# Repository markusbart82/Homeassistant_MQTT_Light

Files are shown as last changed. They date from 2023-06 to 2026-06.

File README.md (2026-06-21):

# Homeassistant MQTT Light
Homeassistant compatible MQTT Light implementation for RGB+CCT LEDs. Uses ESP8266 and PCA9685.

The idea started because I wanted "white with a color tint" smart lights. But apparently, this is not supported by smart home tech yet. It's either RGB, or white, never a mix of these. So this lamp here identifies as RGB, but mixes white with it.

# How Color Mixing Works

This lamp can display both **colored light** and **tunable white** (from warm 2300K to cool 7000K), and uniquely, it can **mix white with color** — producing effects like "pink-tinted white" or "blue-tinted daylight" that most smart lights can't do.

## The Color Pipeline

Here's what happens internally when you send a color command:

1. **Input from Home Assistant**: You send RGB values (0-255) and a color temperature in mireds (142–435 mireds = 7000K–2300K)
2. **White extraction**: The algorithm finds the achromatic (gray/white) component by taking `min(R, G, B)` — this is the amount of white already present in the color
3. **Color separation**: The white component is subtracted from R, G, B, leaving only the pure chromatic (saturated) colors
4. **White distribution**: The extracted white is split between warm white (WW) and cold white (CW) LEDs based on the requested color temperature
5. **PWM output**: All 5 channels (R, G, B, WW, CW) are scaled to 12-bit resolution (0-4095) and sent to the PCA9685 PWM driver

## Examples

### Pure white with temperature
| Input | Output (R,G,B,WW,CW) |
|---|---|
| Warm white (2300K) | (0, 0, 0, 4095, 0) |
| Neutral white | (0, 0, 0, 2048, 2048) |
| Cool white (7000K) | (0, 0, 0, 0, 4095) |

### White with a color tint
| Input | What you see |
|---|---|
| RGB(255,200,200) + 4000K | A soft pink-tinted white |
| RGB(200,220,255) + 5000K | A cool blue-tinted white |
| RGB(255,255,255) + 3500K | Pure warm white (no color tint) |

### Full color
| Input | What you see |
|---|---|
| RGB(255,0,0) + any temp | Pure red (white channels off, `min(255,0,0)=0`) |
| RGB(128,64,32) + 3000K | Orange with warm white boost (`min(128,64,32)=32` → WW adds white) |

## Why This Matters

Traditional smart lights force you to choose: RGB *or* white. With this lamp, you get both simultaneously — perfect for ambient lighting where you want a colored accent light that still feels natural and bright.

# Invisible color temperature updates

Most smart lamps only let you update the color temperature while they are on. So they turn on with the previous color temperature and then dim to the right one. To combat this behavior, send a message with `brightness=1` and the desired color temperature to do an invisible update. The lamp will remain in its previous state (OFF, that is). Such low brightness values usually are not shown in most lamps, either.

# Homeassistant integration

The lamp supports autodiscovery and identifies as "ESP-dimmer-NUMBER", where the number is derived from the MAC address. Supported features:

- JSON schema
- ON/OFF
- Brightness
- Color temperature
- RGB
- Transitions
- Flashing

# Effects

The lamp supports the following effects:

- **Colorwheel** — slowly changes through the RGB spectrum
- **Undulation** — slowly undulates randomly near the previously selected color

# Stand-alone mode

As a fallback when Home Assistant is unavailable:

- On powerup, the lamp turns on with neutral white
- WiFi/MQTT reconnection is handled automatically in the main loop

# Hardware

The lamp uses the PCA9685 PWM driver IC (16 channels, 12 bits, up to 1.5kHz PWM, I2C at 400kHz) to interface with the LEDs. Currently, channels 0–4 are assigned R, G, B, WW, CW.

## Ledcontroller_3x

This PCB includes the ESP8266, PCA9685 and BLM3400 MOSFETs, for controlling 24V LED strips with a common +24V.

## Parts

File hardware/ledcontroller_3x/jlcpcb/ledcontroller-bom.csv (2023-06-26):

Designator | Footprint | Comment | LCSC Part Number
C7,C6,C5,C4,C3 | CP_Elec_5x5.4 | 10uF 35V
R14,R9,R18,R11,R10,R8,R22,R17,R13,R20,R19,R2,R15,R21,R1,R16,R12 | R_0805_2012Metric | 1k
R3,R7,R6,R23,R24,R25,R4,R5 | R_0805_2012Metric | 10k
Q3,Q10,Q4,Q5,Q1,Q11,Q12,Q6,Q7,Q14,Q15,Q13,Q8,Q2,Q9 | SOT-23 | BLM3400
Q16,Q17 | SOT-23 | MMS9013-H-TP
C2,C1 | C_0805_2012Metric | 100nF
U2 | TSSOP-28_4.4x9.7mm_P0.65mm | PCA9685PW

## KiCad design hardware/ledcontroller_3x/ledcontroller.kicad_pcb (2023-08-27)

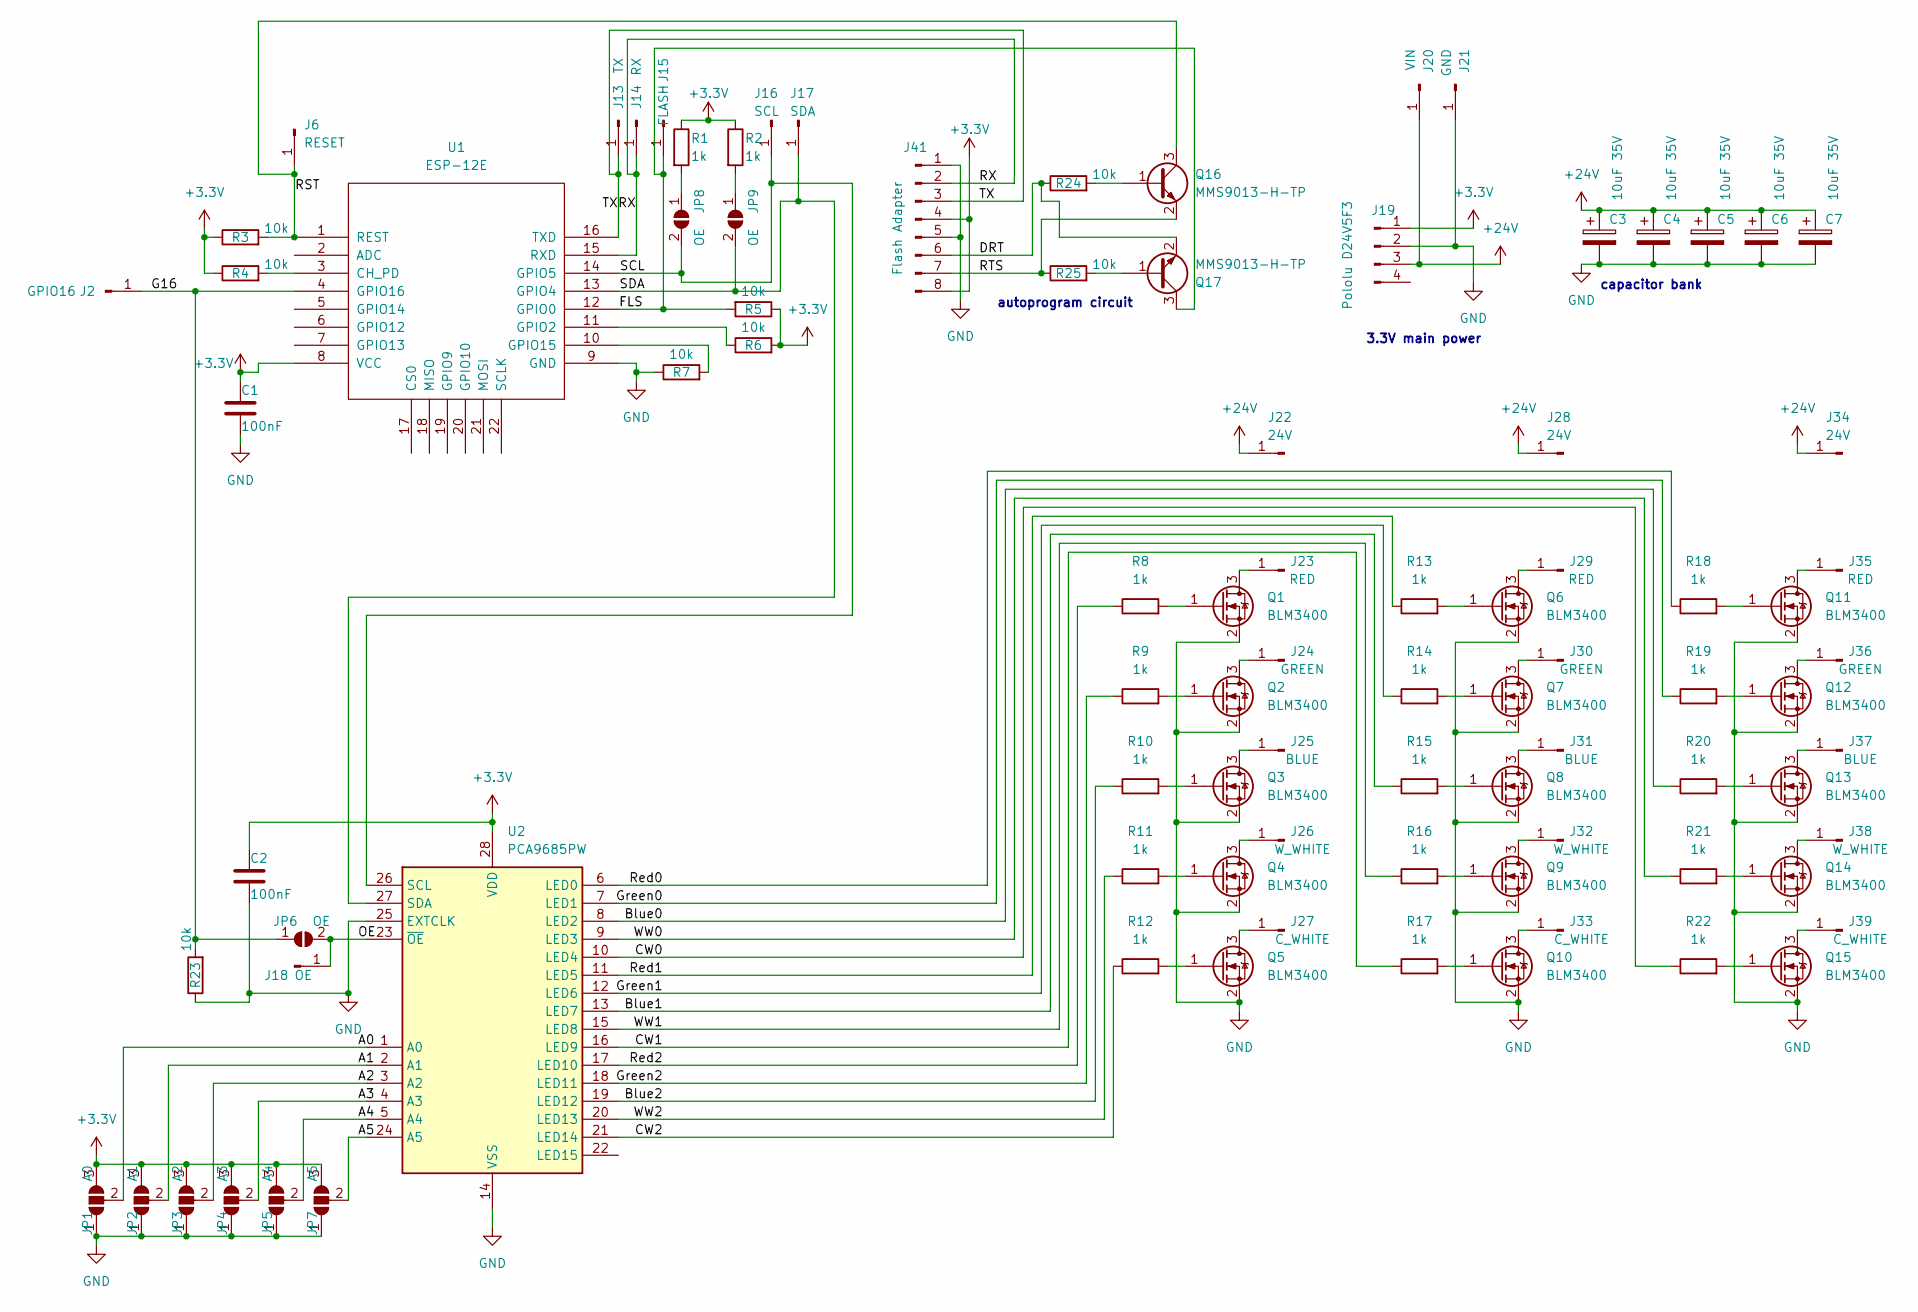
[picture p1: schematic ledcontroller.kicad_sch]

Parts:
C1, C2: 100nF; C_0805_2012Metric
C3, C4, C5, C6, C7: 10uF 35V; CP_Elec_5x5.4
J2: GPIO16; TestPoint_Pad_2.0x2.0mm
J6: RESET; TestPoint_Pad_2.0x2.0mm
J13: TX; TestPoint_Pad_2.0x2.0mm
J14: RX; TestPoint_Pad_2.0x2.0mm
J15: FLASH; TestPoint_Pad_2.0x2.0mm
J16: SCL; TestPoint_Pad_2.0x2.0mm
J17: SDA; TestPoint_Pad_2.0x2.0mm
J18: OE; TestPoint_Pad_2.0x2.0mm
J19: Pololu D24V5F3; PinHeader_1x04_P2.54mm_Vertical
J20: VIN; TestPoint_Pad_4.0x4.0mm
J21: GND; TestPoint_Pad_4.0x4.0mm
J22, J28, J34: 24V; TestPoint_Pad_3.0x3.0mm
J23, J29, J35: RED; TestPoint_Pad_3.0x3.0mm
J24, J30, J36: GREEN; TestPoint_Pad_3.0x3.0mm
J25, J31, J37: BLUE; TestPoint_Pad_3.0x3.0mm
J26, J32, J38: W_WHITE; TestPoint_Pad_3.0x3.0mm
J27, J33, J39: C_WHITE; TestPoint_Pad_3.0x3.0mm
J41: Flash Adapter; WingTAT_ED08BGFBK
JP1: A0; SolderJumper-3_P1.3mm_Open_Pad1.0x1.5mm
JP2: A1; SolderJumper-3_P1.3mm_Open_Pad1.0x1.5mm
JP3: A2; SolderJumper-3_P1.3mm_Open_Pad1.0x1.5mm
JP4: A3; SolderJumper-3_P1.3mm_Open_Pad1.0x1.5mm
JP5: A4; SolderJumper-3_P1.3mm_Open_Pad1.0x1.5mm
JP6, JP8, JP9: OE; SolderJumper-2_P1.3mm_Open_Pad1.0x1.5mm
JP7: A5; SolderJumper-3_P1.3mm_Open_Pad1.0x1.5mm
Q1, Q2, Q3, Q4, Q5, Q6, Q7, Q8, Q9, Q10, Q11, Q12, Q13, Q14, Q15: BLM3400; SOT-23
Q16, Q17: MMS9013-H-TP; SOT-23
R1, R2, R8, R9, R10, R11, R12, R13, R14, R15, R16, R17, R18, R19, R20, R21, R22: 1k; R_0805_2012Metric
R3, R4, R5, R6, R7, R23, R24, R25: 10k; R_0805_2012Metric
U1: ESP-12E; ESP-12E_SMD
U2: PCA9685PW; TSSOP-28_4.4x9.7mm_P0.65mm

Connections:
+3.3V: C1.1, C2.1, J19.1, J41.4, J41.8, JP1.3 (B), JP2.3 (B), JP3.3 (B), JP4.3 (B), JP5.3 (B), JP7.3 (B), R1.1, R2.1, R3.1, R4.1, R5.1, R6.2, U1.8 (VCC), U2.28 (VDD)
+24V: C3.1, C4.1, C5.1, C6.1, C7.1, J19.3, J20.1, J22.1, J28.1, J34.1
/A0: JP1.2 (C), U2.1 (A0)
/A1: JP2.2 (C), U2.2 (A1)
/A2: JP3.2 (C), U2.3 (A2)
/A3: JP4.2 (C), U2.4 (A3)
/A4: JP5.2 (C), U2.5 (A4)
/A5: JP7.2 (C), U2.24 (A5)
/ADC: U1.2 (ADC)
/Blue0: R20.1, U2.8 (LED2)
/Blue1: R15.1, U2.13 (LED7)
/Blue2: R10.1, U2.19 (LED12)
/CS0: U1.17 (CS0)
/CW0: R22.1, U2.10 (LED4)
/CW1: R17.1, U2.16 (LED9)
/CW2: R12.1, U2.21 (LED14)
/DRT: J41.6, Q17.2 (E), R24.1
/FLS: J15.1, Q17.3 (C), R5.2, U1.12 (GPIO0)
/G9: U1.19 (GPIO9)
/G10: U1.20 (GPIO10)
/G12: U1.6 (GPIO12)
/G13: U1.7 (GPIO13)
/G14: U1.5 (GPIO14)
/G16: J2.1, JP6.1 (A), R23.2, U1.4 (GPIO16)
/Green0: R19.1, U2.7 (LED1)
/Green1: R14.1, U2.12 (LED6)
/Green2: R9.1, U2.18 (LED11)
/MISO: U1.18 (MISO)
/MOSI: U1.21 (MOSI)
/OE: J18.1, JP6.2 (B), U2.23 (~OE)
/RST: J6.1, Q16.3 (C), R3.2, U1.1 (REST)
/RTS: J41.7, Q16.2 (E), R25.1
/RX: J14.1, J41.2, U1.15 (RXD)
/Red0: R18.1, U2.6 (LED0)
/Red1: R13.1, U2.11 (LED5)
/Red2: R8.1, U2.17 (LED10)
/SCL: J16.1, JP8.2 (B), U1.14 (GPIO5), U2.26 (SCL)
/SCLK: U1.22 (SCLK)
/SDA: J17.1, JP9.2 (B), U1.13 (GPIO4), U2.27 (SDA)
/TX: J13.1, J41.3, U1.16 (TXD)
/WW0: R21.1, U2.9 (LED3)
/WW1: R16.1, U2.15 (LED8)
/WW2: R11.1, U2.20 (LED13)
GND: C1.2, C2.2, C3.2, C4.2, C5.2, C6.2, C7.2, J19.2, J21.1, J41.1, J41.5, JP1.1 (A), JP2.1 (A), JP3.1 (A), JP4.1 (A), JP5.1 (A), JP7.1 (A), Q1.2 (S), Q2.2 (S), Q3.2 (S), Q4.2 (S), Q5.2 (S), Q6.2 (S), Q7.2 (S), Q8.2 (S), Q9.2 (S), Q10.2 (S), Q11.2 (S), Q12.2 (S), Q13.2 (S), Q14.2 (S), Q15.2 (S), R7.1, R23.1, U1.9 (GND), U2.14 (VSS), U2.25 (EXTCLK)
unnamed: J23.1, Q1.3 (D)
unnamed: J24.1, Q2.3 (D)
unnamed: J25.1, Q3.3 (D)
unnamed: J26.1, Q4.3 (D)
unnamed: J27.1, Q5.3 (D)
unnamed: J29.1, Q6.3 (D)
unnamed: J30.1, Q7.3 (D)
unnamed: J31.1, Q8.3 (D)
unnamed: J32.1, Q9.3 (D)
unnamed: J33.1, Q10.3 (D)
unnamed: J35.1, Q11.3 (D)
unnamed: J36.1, Q12.3 (D)
unnamed: J37.1, Q13.3 (D)
unnamed: J38.1, Q14.3 (D)
unnamed: J39.1, Q15.3 (D)
unnamed: JP8.1 (A), R1.2
unnamed: JP9.1 (A), R2.2
unnamed: Q1.1 (G), R8.2
unnamed: Q2.1 (G), R9.2
unnamed: Q3.1 (G), R10.2
unnamed: Q4.1 (G), R11.2
unnamed: Q5.1 (G), R12.2
unnamed: Q6.1 (G), R13.2
unnamed: Q7.1 (G), R14.2
unnamed: Q8.1 (G), R15.2
unnamed: Q9.1 (G), R16.2
unnamed: Q10.1 (G), R17.2
unnamed: Q11.1 (G), R18.2
unnamed: Q12.1 (G), R19.2
unnamed: Q13.1 (G), R20.2
unnamed: Q14.1 (G), R21.2
unnamed: Q15.1 (G), R22.2
unnamed: Q16.1 (B), R24.2
unnamed: Q17.1 (B), R25.2
unnamed: R4.2, U1.3 (CH_PD)
unnamed: R6.1, U1.11 (GPIO2)
unnamed: R7.2, U1.10 (GPIO15)

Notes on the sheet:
capacitor bank
autoprogram circuit
3.3V main power

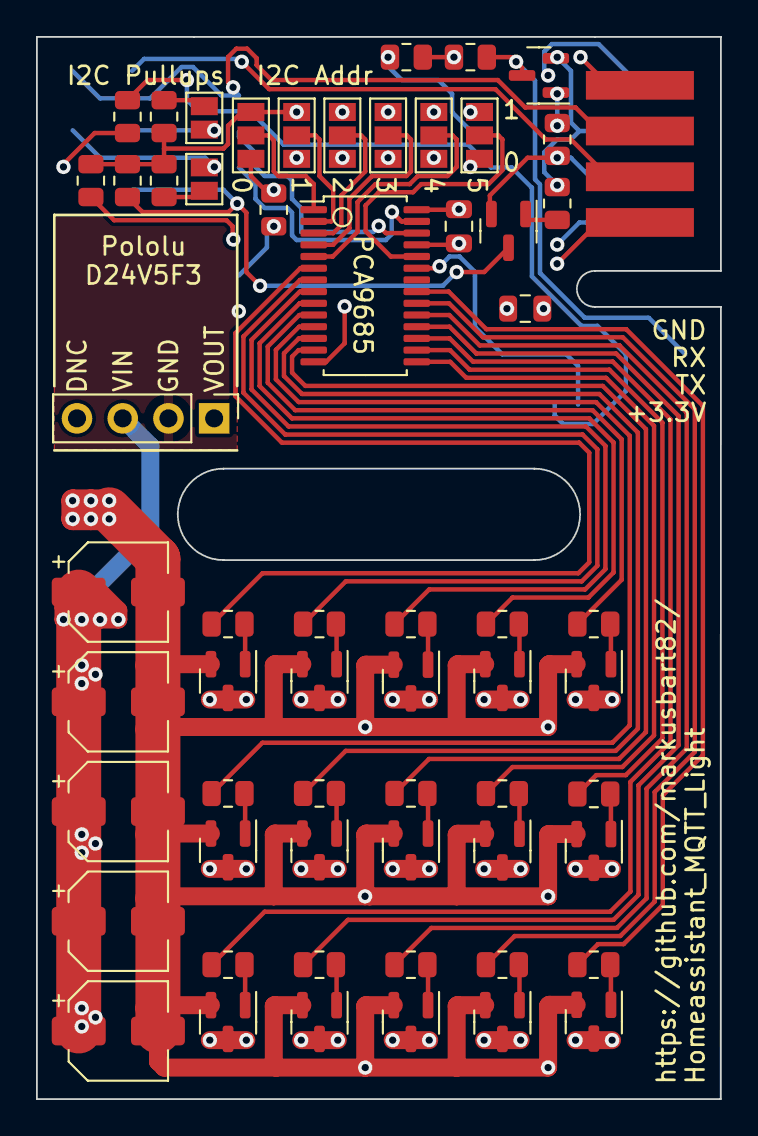
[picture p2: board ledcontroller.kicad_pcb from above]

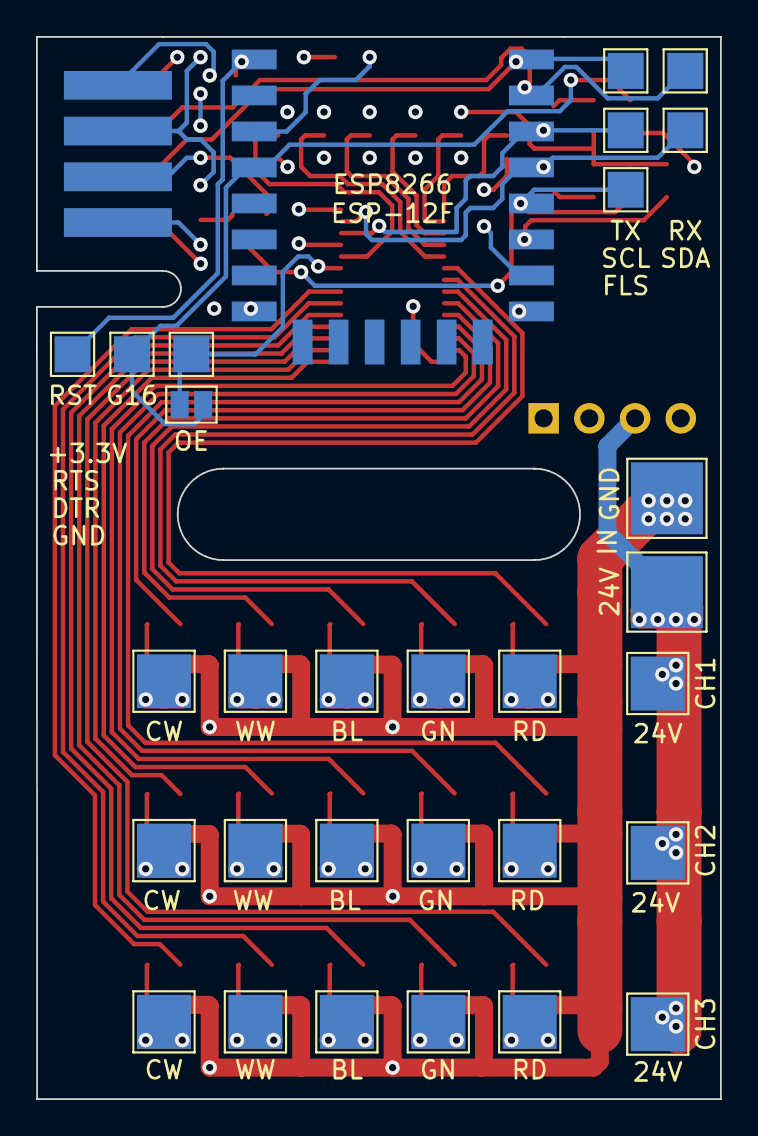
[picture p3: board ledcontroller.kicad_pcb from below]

Board: 4 copper layers, 38.0 x 59.0 mm, 90 parts (30 on the bottom side), 71 nets.

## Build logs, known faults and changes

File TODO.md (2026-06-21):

# Get LEDs to light up correctly
* Is library called correctly?
* Are color values calculated correctly? Repeated "ON" commands lead to different white balance...

# Unburden the ISR for receiving a message
* add MessageHandler buffer to store received message and to process it later, during main loop
* add "memory busy" flag to avoid overwriting this buffer if messages come in too quickly (is this an issue?)

# Fix errors
* find cause for random reconnects (Wifi)

# Cleanup
* remove printlns from Channelmanager::loop()

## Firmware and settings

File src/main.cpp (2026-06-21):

#include <Arduino.h>
#include <ESP8266WiFi.h>
#include <PubSubClient.h>
#include <PCA9685.h>
#include "ArduinoJson.h"
#include "secrets.h"
#include "channel.h"
#include "channelmanager.h"
#include "colorhandler.h"
#include "messagehandler.h"
#include "controller.h"
#include "types.h"


// output enable (low = enabled)
#define OE_PIN 16

// I2C
#define SCL_PIN 5
#define SDA_PIN 4

Channelmanager channelmanager(3); // TODO: make this dynamic - for now, it's 3 static channels
Messagehandler messagehandler;
WiFiClient wifiClient;
PubSubClient pubSubClient(wifiClient);

// this function is the entry point for received messages
void receiveMessage(char* topic, byte* payload, unsigned int length) {
  Serial.println("receiveMessage");

  /* HomeAssistant will send these messages to the lamp using the UI:
   * OFF
   * ON
   * ON brightness
   * ON colortemp
   * ON RGB
   * ON effect
   * 
   * HomeAssistant will send these messages to the lamp using scripts:
   * ON brightness colortemp
   * ON transition
   * OFF transition
   * ON transition brightness
   * ON transition colortemp
   * ON transition brightness colortemp
   * ON flash RGB
   * ON flash brightness
   * ON flash colortemp
   * ON flash brightness colortemp
   * 
   * HomeAssistant will NOT send these messages:
   * OFF colortemp
   * ON brightness=0 colortemp
   * 
   * This lamp will use this message format to change the colortemp without turning on the lamp:
   * ON brightness=1 colortemp
   * And after the call, it reports back "OFF"
   */

  //TODO: move all of the following into the main loop, inside messageHandler.parseMessage, and have a buffer for the received values
   
  // call messagehandler to parse the message
  messagehandler.parseMessage(topic, payload, length);

  // temporary values for updating the channel
  uint16_t r = 0;
  uint16_t g = 0;
  uint16_t b = 0;
  uint16_t ww = 0;
  uint16_t cw = 0;
  uint8_t channelNumber = messagehandler.getChannelNumber();
  boolean writeUpdate = true; // set this variable to false if an update is not required

  // update channel(s) with data from the parsed message
  Channel* channel = channelmanager.getChannel(channelNumber);
  // check on/off state
  if(messagehandler.getState()){
    Serial.println("state is ON");
    // state is "ON"

    if(messagehandler.getEffect() != none){
      Serial.println("has effect");
      
      // if an effect is selected, use that
      channel->setEffect(messagehandler.getEffect());

    }else{
      Serial.println("has no effect");
      
      // if no effect is selected, disable effects and proceed
      channel->setEffect(none);

      // if color temperature is included, update the stored value
      if(messagehandler.getColortemp()!=UINT16_MAX){
        channel->setColorTemp(messagehandler.getColortemp());
      }

      // calculate colors to use for dim/flash
      if(messagehandler.getBrightness()>0){
        Serial.println("using brightness mode");
        // brightness is part of the message, go for uncolored mode
        if(messagehandler.getBrightness()==1){
          // special message to update color temperature and change nothing in the actual light
          writeUpdate = false; // do nothing, no changes to the light, just update the color temperature
        }else{
          // brightness >1, use it for RGB with stored color temperature
          uint8_t brightness = messagehandler.getBrightness();
          Colorhandler::rgb8ToRgbww12(brightness, brightness, brightness, channel->getColorTemp(), r, g, b, ww, cw);
        }
      }else if(messagehandler.getRed()>0 || messagehandler.getGreen()>0 || messagehandler.getBlue()>0){
        Serial.println("using RGB mode");
        // RGB is set, use it with stored color temperature
        Colorhandler::rgb8ToRgbww12(messagehandler.getRed(), messagehandler.getGreen(), messagehandler.getBlue(), channel->getColorTemp(), r, g, b, ww, cw);
      }else{
        // just "ON" command
        Colorhandler::rgb8ToRgbww12(255u, 255u, 255u, channel->getColorTemp(), r, g, b, ww, cw);
      }

      // dim or flash the lamp accordingly
      if(writeUpdate){ // skip the update for the invisible colortemp update
        if(messagehandler.getFlashTime()>0){
          Serial.println("flashing");
          // flashing
          channel->flashColor(r, g, b, ww, cw, messagehandler.getFlashTime());
        }else{
          Serial.println("dimming");
          // dimming
          channel->dimToColor(r, g, b, ww, cw, messagehandler.getTransitionTime());
        }
      }
    }
  }else{
    Serial.println("state is OFF");
    // state is "OFF"
    // turn off the lamp
    channel->dimToColor(0, 0, 0, 0, 0, messagehandler.getTransitionTime());
  }

  // send state message back to HomeAssistant server
  // convert to 8bit values before reporting them back to home assistant
  uint8_t r8 = 0;
  uint8_t g8 = 0;
  uint8_t b8 = 0;
  uint16_t ct16 = 0;
  Colorhandler::rgbww12ToRgb8(r, g, b, ww, cw, r8, g8, b8, ct16);
  messagehandler.sendStateMessage(pubSubClient, channelNumber, r8, g8, b8, ct16, messagehandler.getEffect());
  
}

void setup() {
  // configure pins
  pinMode(SCL_PIN, OUTPUT);
  pinMode(SDA_PIN, OUTPUT);
  pinMode(OE_PIN, OUTPUT);
  pinMode(LED_BUILTIN, OUTPUT);

  // start I2C bus
  Wire.begin();
  Wire.setClock(400000); // PCA9685 supports up to 1 MHz (yet we currently use 400kHz for debugging)
  
  // init serial console
  Serial.begin(115200);
  delay(100);

  // init channel manager (thereby initializing physical controllers)
  channelmanager.init();

  // init wifi
  Serial.println("Connecting to WIFI");
  WiFi.begin(SSID, PSK);
  while (WiFi.status() != WL_CONNECTED) {
    delay(100);
  }
  Serial.println("WIFI connection established");

  // read mac address from wifi for unique names
  messagehandler.init();
  messagehandler.getMacAddress();

  // configure MQTT broker
  pubSubClient.setServer(MQTT_BROKER, 1883);
  pubSubClient.setCallback(receiveMessage);
  pubSubClient.setBufferSize(500);

  // random number generator
  randomSeed(analogRead(A0));

  // turn off internal LED
  digitalWrite(LED_BUILTIN, HIGH);

  // enable outputs
  digitalWrite(OE_PIN, LOW);

  // TODO: do other initialization stuff
}


void loop() {
  // WiFi reconnection (non-blocking, single attempt per iteration)
  if (WiFi.status() != WL_CONNECTED) {
    WiFi.begin(SSID, PSK);
    Serial.println("Reconnecting to WIFI");
  }

  // MQTT reconnection (non-blocking, single connect() call per iteration)
  if (!pubSubClient.connected()) {
    if (pubSubClient.connect(messagehandler.getClientName(), MQTT_USER, MQTT_PASS)) {
      Serial.println("MQTT connection established");
      Serial.println("Sending auto discovery message to Home Assistant");
      messagehandler.sendAutoDiscoveryMessage(pubSubClient, 3u); // TODO: make this dynamic - for now, it's 3 static channels
      channelmanager.requestUpdate();
      Serial.println("Home Assistant configured");
    } else {
      Serial.println("MQTT connection failed");
    }
  }

  // Execute connection-dependent code only when both WiFi and MQTT are connected
  if (WiFi.status() == WL_CONNECTED && pubSubClient.connected()) {
    // update channels, do all the dimming etc. and send commands to physical controllers
    channelmanager.loop();

    // parse incoming messages for MQTT
    pubSubClient.loop();
  }
}

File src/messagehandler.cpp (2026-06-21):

// parses incoming MQTT messages and extracts data, creates outgoing MQTT messages from internal data

#include "messagehandler.h"

// constructor
Messagehandler::Messagehandler(){
}

// initialization of internal structures
void Messagehandler::init(){
}

// get mac address to use as part of the device name (and set client name)
void Messagehandler::getMacAddress(){
  // this stupid mac address trickery seems to be necessary because there seems to be no working conversion between unsigned char[] and char[]
  unsigned char mac[6];
  WiFi.macAddress(mac);
  int macNum = mac[0]*100000 + mac[1]*10000 + mac[2]*1000 + mac[3]*100 + mac[4]*10 + mac[5];
  itoa(macNum, this->macAddressUid, 10);

  // now that all necessary info is present, set the client name
  strcpy(mqttClientName, clientNamePrefix);
  strcat(mqttClientName, macAddressUid);
}

// create and send autodiscovery message for given number of channels and subscribe to command topics
void Messagehandler::sendAutoDiscoveryMessage(PubSubClient &client, uint8_t numberOfChannels){
  // loop over all channels, send an autodiscovery message for each one
  Serial.print("sendAutoDiscoveryMessage(");
  Serial.print(numberOfChannels);
  Serial.println(")");
  for(uint8_t channelNumber = 0; channelNumber < numberOfChannels; channelNumber++){
    Serial.print("Channel ");
    Serial.println(channelNumber);
    // get channel number as a char array
    itoa(channelNumber, chNum, 10);
    // assemble config topic
    strcpy(configTopic, topicPrefix);
    strcat(configTopic, macAddressUid);
    strcat(configTopic, chInfix);
    strcat(configTopic, chNum);
    strcat(configTopic, topicPostfixConfig);
    Serial.println(configTopic);
    // assemble command topic
    strcpy(commandTopic, topicPrefix);
    strcat(commandTopic, macAddressUid);
    strcat(commandTopic, chInfix);
    strcat(commandTopic, chNum);
    strcat(commandTopic, topicPostfixCommand);
    Serial.println(commandTopic);
    // assemble and send  config message
    uint16_t configMessageLength = 0;
    configMessageLength += strlen(configMsgPart1);
    configMessageLength += strlen(configMsgPart2);
    configMessageLength += strlen(configMsgPart3);
    configMessageLength += strlen(configMsgPart4);
    configMessageLength += strlen(configMsgPart5);
    configMessageLength += strlen(configMsgPart6);
    configMessageLength += strlen(configMsgPart7);
    configMessageLength += (6 * strlen(macAddressUid)); // mac address is in the message 6 times
    configMessageLength += (4 * strlen(chInfix)); // channel infix is in the message 4 times
    configMessageLength += 4; // channel number (uint8_t) is in the message 4 times
    client.beginPublish(configTopic, configMessageLength, true);
    client.write((const unsigned char*) configMsgPart1, strlen(configMsgPart1));
    client.write((const unsigned char*) macAddressUid, strlen(macAddressUid));
    client.write((const unsigned char*) chInfix, strlen(chInfix));
    client.write((const unsigned char*) chNum, strlen(chNum));
    client.write((const unsigned char*) configMsgPart2, strlen(configMsgPart2));
    client.write((const unsigned char*) macAddressUid, strlen(macAddressUid));
    client.write((const unsigned char*) chInfix, strlen(chInfix));
    client.write((const unsigned char*) chNum, strlen(chNum));
    client.write((const unsigned char*) configMsgPart3, strlen(configMsgPart3));
    client.write((const unsigned char*) macAddressUid, strlen(macAddressUid));
    client.write((const unsigned char*) configMsgPart4, strlen(configMsgPart4));
    client.write((const unsigned char*) macAddressUid, strlen(macAddressUid));
    client.write((const unsigned char*) configMsgPart5, strlen(configMsgPart5));
    client.write((const unsigned char*) macAddressUid, strlen(macAddressUid));
    client.write((const unsigned char*) chInfix, strlen(chInfix));
    client.write((const unsigned char*) chNum, strlen(chNum));
    client.write((const unsigned char*) configMsgPart6, strlen(configMsgPart6));
    client.write((const unsigned char*) macAddressUid, strlen(macAddressUid));
    client.write((const unsigned char*) chInfix, strlen(chInfix));
    client.write((const unsigned char*) chNum, strlen(chNum));
    client.write((const unsigned char*) configMsgPart7, strlen(configMsgPart7));
    client.endPublish();
    // subscribe to command topic
    client.subscribe(commandTopic);
  }
}

// create and send state message for one channel (RGB + colortemp)
void Messagehandler::sendStateMessage(PubSubClient &client, uint8_t channelNumber, uint8_t r, uint8_t g, uint8_t b, uint8_t ct, effect_t fx){
  Serial.println("sendStateMessage");
  //JsonDocument message;
  StaticJsonDocument<512> message;
  if(r==0 && g==0 && b==0){
    message["state"] = "OFF";
  }else{
    message["state"] = "ON";
    if(r==g && g==b){
      // if r,g,b are identical --> send brightness/colortemp
      message["brightness"] = (r+g+b)/3;
      message["color_temp"] = Colorhandler::kelvinToMireds(ct);
    }else{
      // if r,g,b are different --> send RGB
      message["color"]["r"] = r;
      message["color"]["g"] = g;
      message["color"]["b"] = b;
    }
    switch(fx){
      case colorwheel:
        message["effect"] = "colorwheel";
        break;
      case undulation:
        message["effect"] = "undulation";
        break;
      default:
        message["effect"] = "none";
        break;
    }
  }
  char output[128];
  serializeJson(message, output);
  // get channel number as a char array
  itoa(channelNumber, chNum, 10);
  // assemble state topic
  strcpy(stateTopic, topicPrefix);
  strcat(stateTopic, macAddressUid);
  strcat(stateTopic, chInfix);
  strcat(stateTopic, chNum);
  strcat(stateTopic, topicPostfixState);
  // send message
  client.publish(stateTopic,output,true);
}
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

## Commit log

2023-03-12 added ledcontroller_3x
    [ledcontroller-bom.csv, ledcontroller.kicad_pcb, ledcontroller.kicad_sch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]
2023-03-12 added stand-alone mode and wifi switch
2023-04-10 Updated PCB to combat flickering with higher current LEDs or longer strips
    [ledcontroller-bom.csv, ledcontroller.kicad_pcb, ledcontroller.kicad_sch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]
2023-04-10 Removed sensor inputs - these should be a separate device. Also, improved the standalone mode time to light the default setting.
2023-05-06 Updated PCB: additional decoupling capacitors, switchable I2C pullups, made OE pulled down instead of pulled up
    [ledcontroller-bom.csv, ledcontroller.kicad_pcb, ledcontroller.kicad_sch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]
2023-06-20 replaced ceramic capacitors with low ESR electrolytic caps
    [ledcontroller.kicad_pcb, ledcontroller.kicad_sch]
2023-06-20 added autoprogram circuit to schematic
    [ledcontroller.kicad_sch]
2023-06-25 Added PCB Edge Connector for programming, rearranged lots of parts, removed pads of unused GPIOs
    [ledcontroller.kicad_pcb, ledcontroller.kicad_sch]
2023-06-26 PCB export for JLCPCB
    [ledcontroller-bom.csv, ledcontroller.kicad_pcb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]
2023-08-27 fixed typo in silkscreen
    [ledcontroller.kicad_pcb]
2024-06-23 PCB updates
2024-06-23 code re-write for maintainability (aka "I broke everything")
    [channel.cpp, channel.h, channelmanager.cpp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]
2024-07-20 Fixed warnings from ArduinoJson 6 to 7 upgrade
    [messagehandler.cpp]
2024-07-20 added TODOs to fix later
    [main.cpp, messagehandler.h]
2024-08-03 added auto-generated client name, fixed pubSubClient connection
    [main.cpp, messagehandler.cpp, messagehandler.h]
2024-08-03 ArduinoJson migration StaticJsonDocument to JsonDocument
2024-08-18 fixed colortemp conversion functions' definitions
    [colorhandler.cpp]
2026-06-21 various fixes, debug output in many places
    [channel.cpp, channel.h, channelmanager.cpp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]
